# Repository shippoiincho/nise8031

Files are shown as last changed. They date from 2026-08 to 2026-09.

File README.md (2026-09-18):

# PC-8031 Emulator 偽8031

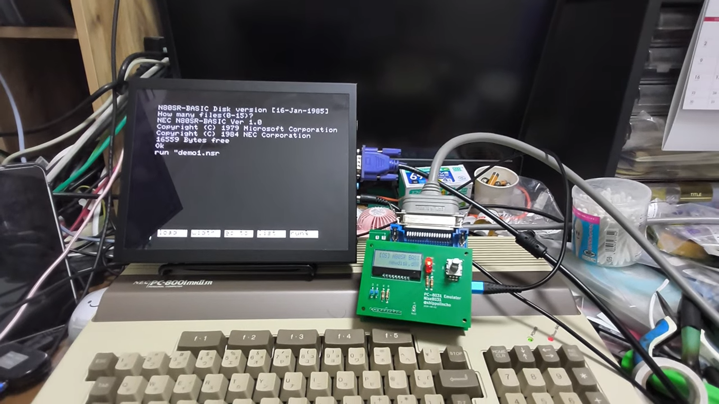
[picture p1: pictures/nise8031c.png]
board


---
# これはなに

PC-8001/8801 シリーズ用の 5インチフロッピードライブ、PC-8031 シリーズのエミュレータです。
2D ドライブのエミュレーションを行います。(PC-80S31 など相当)

PC-8001mk2SR と PC-6001mk2SR で動作確認しています。
PC-8801 でも動くと思いますが未確認です。

---
# 配線

今回はかなり複雑なので配線などは回路図を参照ください。

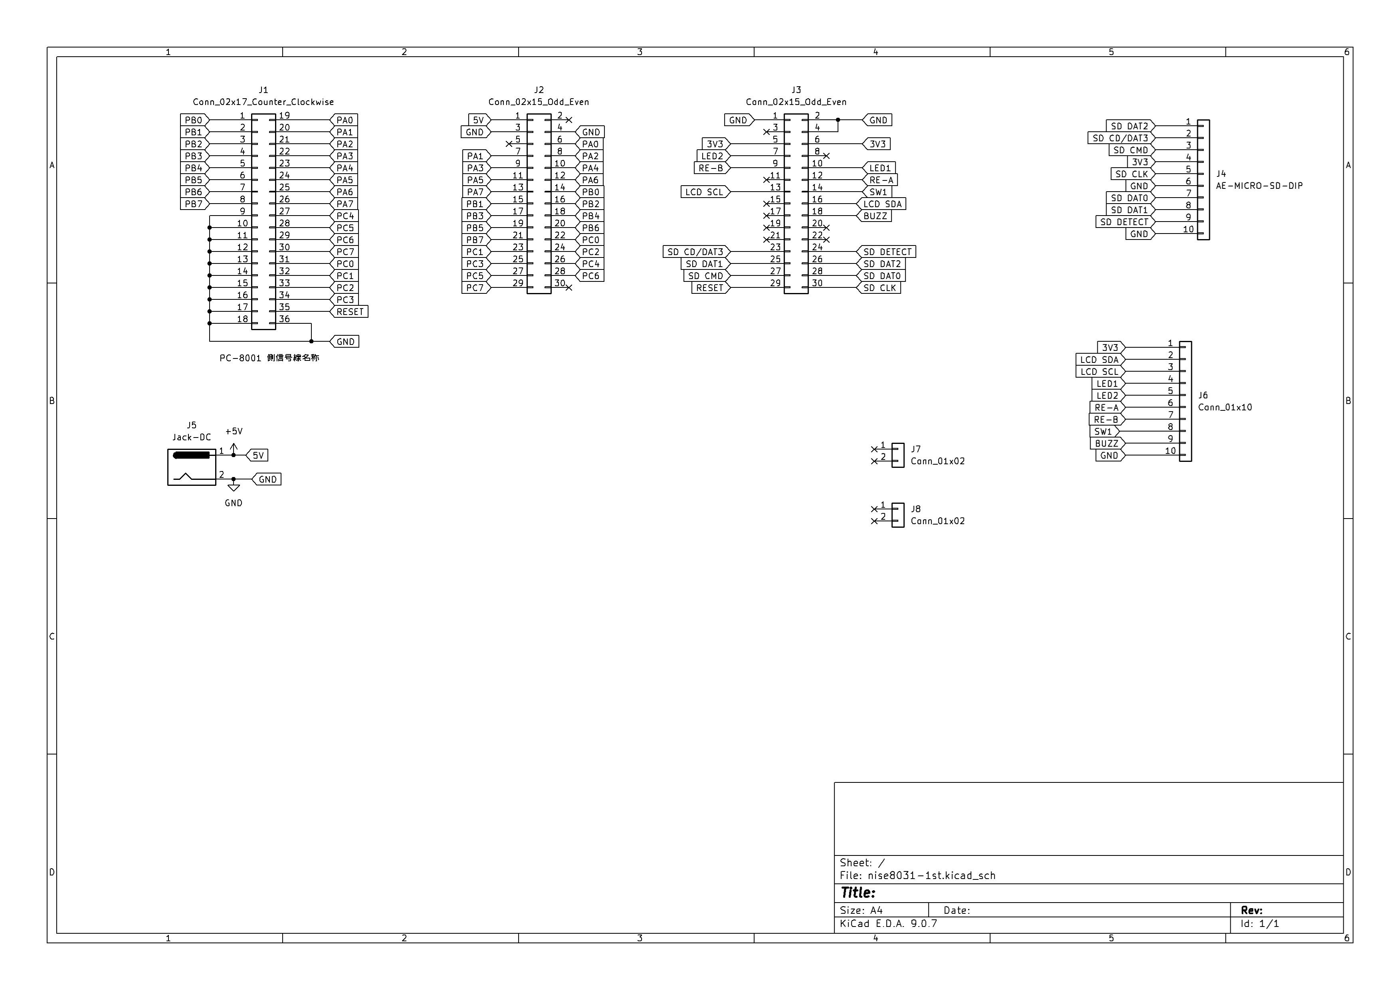
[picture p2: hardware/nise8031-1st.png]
schematics 1st

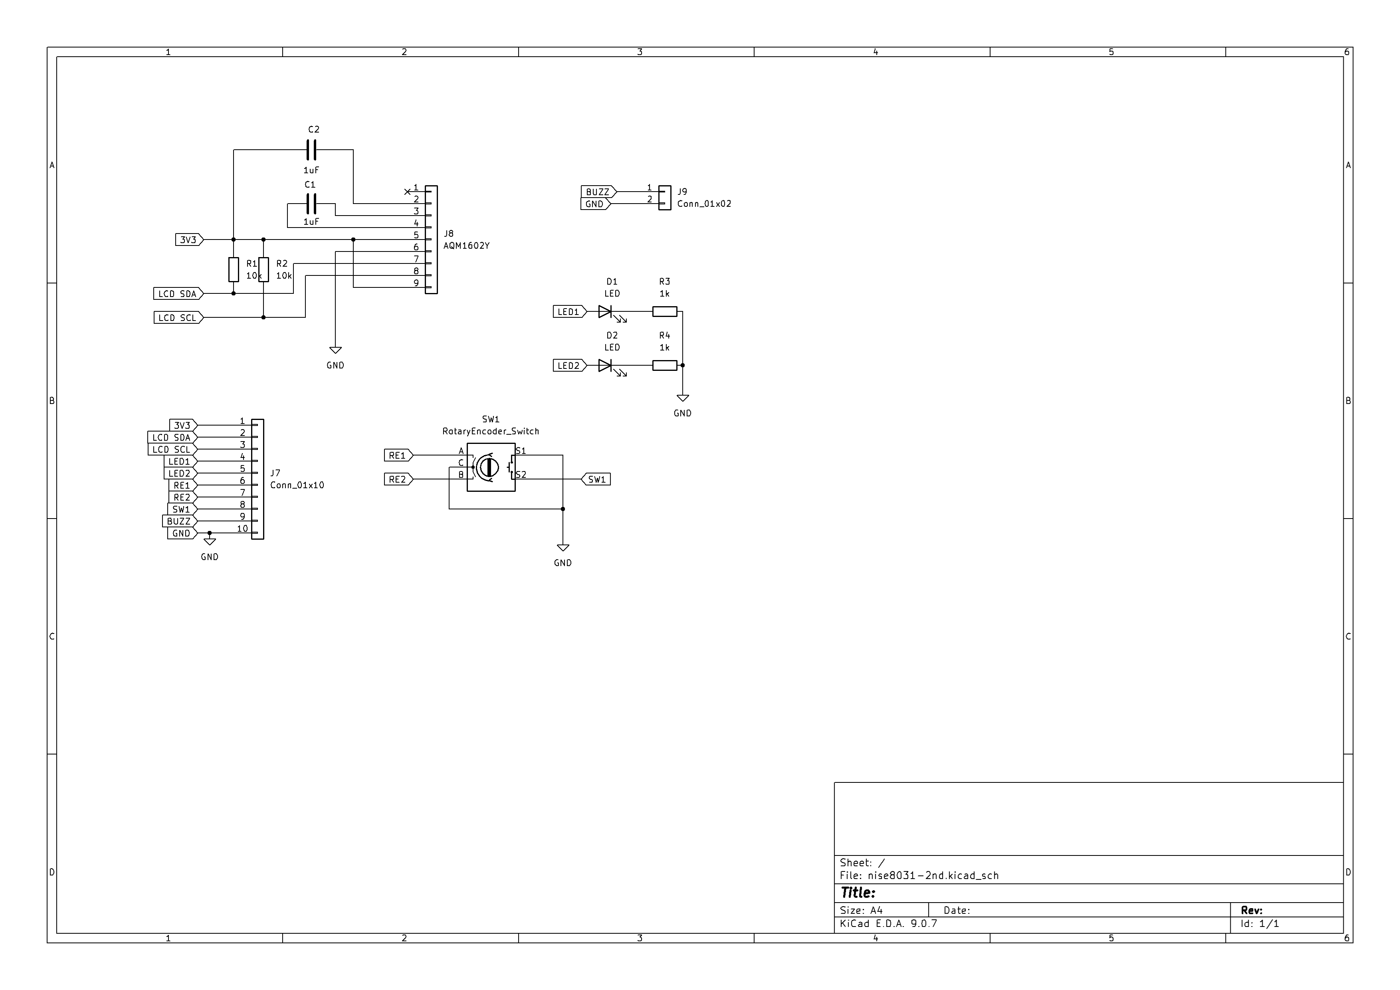
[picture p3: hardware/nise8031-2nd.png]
schematics 2nd


発注に必要な基板データは `hardware` の下にあります。

必要なパーツは以下の通りです。

- WeAct RP2350B Core Board
- [microSD DIP 化基板](https://akizukidenshi.com/catalog/g/g105488/)
- [AQM1602Y-RN-GBW](https://akizukidenshi.com/catalog/g/g111916/)
- アクセスランプ用 LED (3mm でも 5mm でもOK)
- ロータリーエンコーダ (SW 付き)
- 抵抗 1K/10K
- アンフェノールコネクタ 34Pin
- ピンヘッダ＆ソケット(基板間接続用)

基板データ上は AC アダプタの端子がありますが、
電源供給は、Pico の USB 端子を想定しています。

完成すると以下のようになるかと思います。

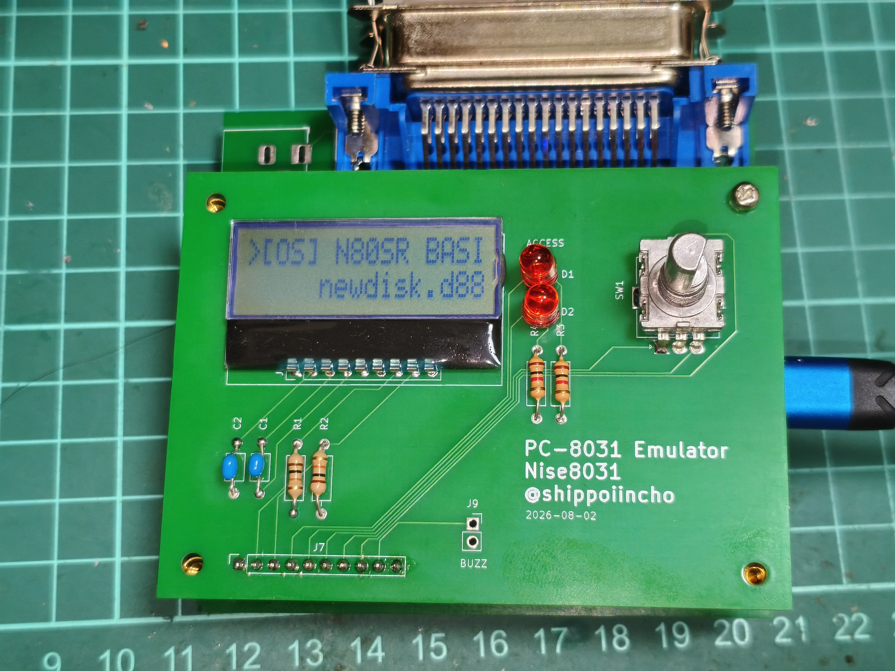
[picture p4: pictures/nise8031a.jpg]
board 2nd

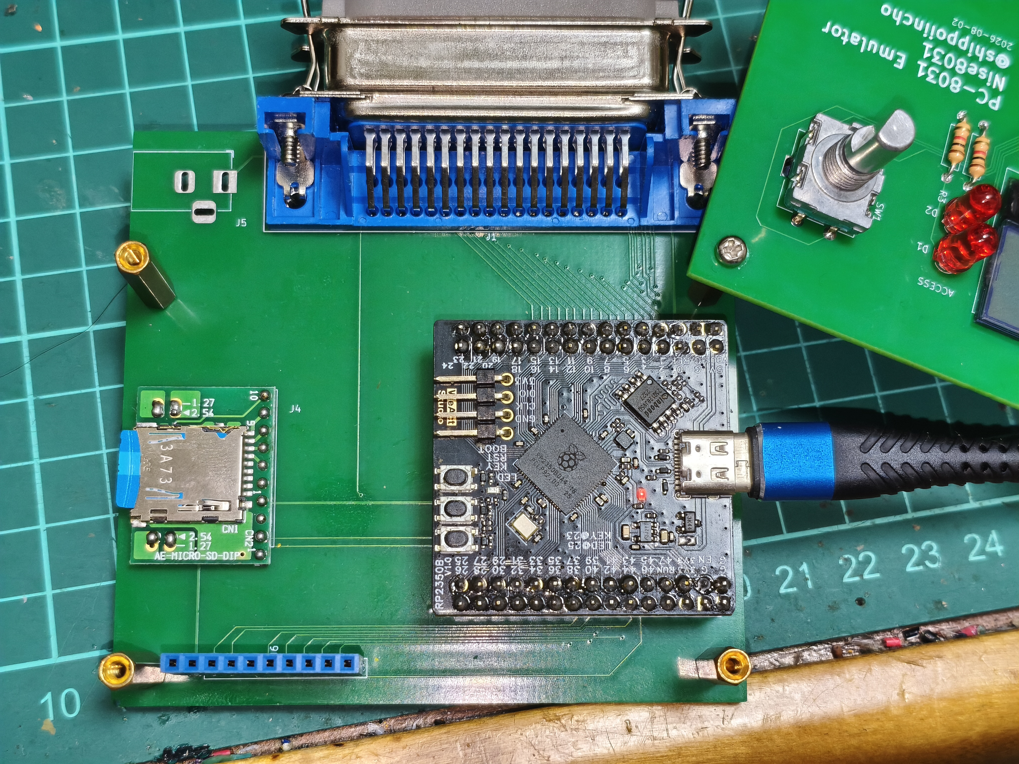
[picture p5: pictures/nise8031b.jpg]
board 1st


同じく hardware フォルダの中に、ケース用の 3Dプリンタ用データがありますので、必要であればご使用ください。
このデータは基板間を 20mm のスペーサで保持するように設計されています。
この場合基板間接続には足の長いソケットを使うとよいと思います。
(例:https://akizukidenshi.com/catalog/g/g107914/)

---
# FIRMWARE

`nise8031.uf2` を Pico のフラッシュに書き込んでください。

---
# ROM など

著作権の関係で ROM は含まれていません。

PC-80S31 (2KiB) および、PC-8801MA (8KiB) の disk.rom での動作を確認しています。
ROM ファイルを `disk.rom` というファイル名で、SD カードのルートディレクトリに置いてください。

[PC-8801 エミュレータ M88 用の pseudo bios ](http://retropc.net/cisc/m88/download.html)にも対応しました。
2D メディア専用ですが、PC-8031 シリーズ実機の ROM がなくても動作します。

---
# ディスクイメージ

エミュレータでよく使用される D88 フォーマットファイルを使用します。
microSD カード上に D88 ファイルを置いておきます。

PC-6001mk2SR 用の 1DD イメージは、内部で 2D イメージとして操作しますので、そのまま使用できると思います。

---
# 操作方法

ロータリーエンコーダを使って操作します。
基本的に回転でファイルやディレクトリを選択して、スイッチで選んだファイルやディレクトリをマウントします。
ディレクトリは `[DIR]` のように表示されます。

内部的にファイル名は 254 文字まで対応していますが、画面上では 15 文字までしか表示されません。
また`[UNMOUNT]`を選択すると、そのドライブからイメージファイルをアンマウントします。

---
# 制限事項

- フロッピーのフォーマット(しれっと無視します)は未実装です。ブランクのディスクイメージはあらかじめパソコン上のエミュレータでフォーマットしておく必要があります。
- FDC の一部のコマンドしか実装していないので、FDC を直接操作するソフトは動かない可能性があります。
- FD の動作は一瞬で完了する実装になっています。タイミングが必要なソフトで不具合が出る可能性があります。
- まれに本体起動時のハンドシェイクに失敗します。本体をリセットしなおすと起動すると思います。

---
# ライセンスなど

このエミュレータは以下のライブラリを使用しています。

- [Z80](https://github.com/redcode/Z80/tree/master)
- [Zeta](https://github.com/redcode/Zeta)
- [no-OS-FatFS-SD-SDIO-SPI-RPi-Pico](https://github.com/carlk3/no-OS-FatFS-SD-SDIO-SPI-RPi-Pico)

---

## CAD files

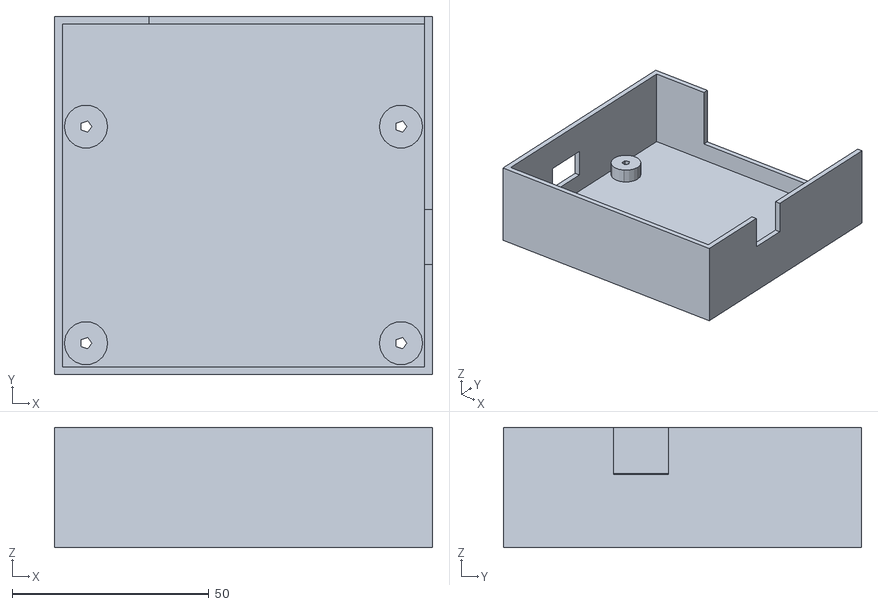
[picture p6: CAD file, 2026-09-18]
hardware/nise8031case_bottom.stl
96.0 x 91.0 x 30.6

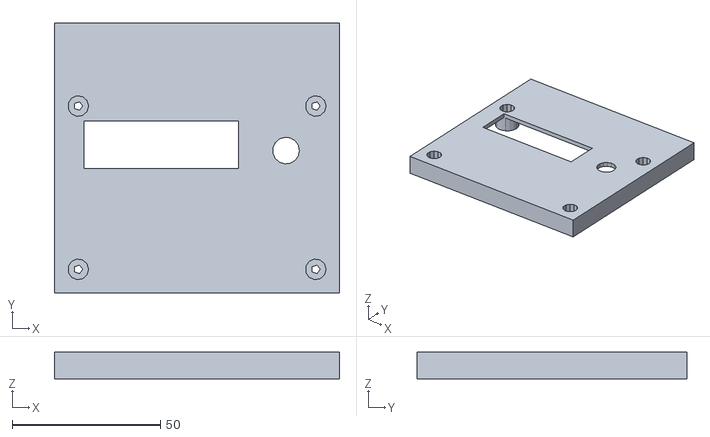
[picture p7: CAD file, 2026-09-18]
hardware/nise8031case_upper.stl
96.0 x 91.0 x 9.00

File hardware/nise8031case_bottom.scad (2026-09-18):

// nise8031 case bottom
// Base = top of 2nd floor
// Spacing of PCB = 20mm
// Shell wide = 2mm
// Bottom space = 5mm

// Bottom Outer

PCBW=1.8;
PCBS=20;
SPACE=5;
SHELLW=2.0;

difference() {



translate([-46-SHELLW,-43.5-SHELLW,-(PCBW*2+PCBS+SPACE+SHELLW)]) {    
cube([92+SHELLW*2,87+SHELLW*2,(PCBW*2+PCBS+SPACE+SHELLW)]);
};

{
translate([-46,-43.5,-(PCBW*2+PCBS+SPACE)]) {  
cube([92,87,(PCBW*2+PCBS+SPACE)]);
}

// FD connector
translate([-24,43.5,-(PCBW+PCBS)]) {       
cube([70,2,(PCBW+PCBS)]);    
}

// USB port

translate([46,-43.5+26,-12]) {
cube([2,14,12]);
}

translate([-46-SHELLW,-43.5+25,-(PCBW*2+PCBS+SPACE)+SPACE+PCBW]) {
cube([2,16,10]);
}

// SD card

// LINE OUT

//translate([-1,25,-2]) {
//
//cube([10,6,2]);
//
//}

// Bottom Holes

translate([-40,-37.5,-(PCBW*2+PCBS+SPACE+SHELLW)]) {
    
cylinder(5-SHELLW,3.5,3.5);    
       
}

translate([+40,-37.5,-(PCBW*2+PCBS+SPACE+SHELLW)]) {
    
cylinder(5-SHELLW,3.5,3.5);    
       
}

translate([-40,-37.5+55,-(PCBW*2+PCBS+SPACE+SHELLW)]) {
    
cylinder(5-SHELLW,3.5,3.5);    
       
}

translate([+40,-37.5+55,-(PCBW*2+PCBS+SPACE+SHELLW)]) {
    
cylinder(5-SHELLW,3.5,3.5);    
       
}

}
}

translate([-40,-37.5,-(PCBW*2+PCBS+SPACE)]) {

difference() {
    
cylinder(5,5.5,5.5);   
   {
    cylinder(5,1.5,1.5); 
    cylinder(5-SHELLW,3.5,3.5);     
   }
       
}
    
};

translate([+40,-37.5,-(PCBW*2+PCBS+SPACE)]) {

difference() {
    
cylinder(5,5.5,5.5);   
   {
    cylinder(5,1.5,1.5); 
    cylinder(5-SHELLW,3.5,3.5);     
   }
       
}
    
};

translate([-40,-37.5+55,-(PCBW*2+PCBS+SPACE)]) {

difference() {
    
cylinder(5,5.5,5.5);   
   {
    cylinder(5,1.5,1.5); 
    cylinder(5-SHELLW,3.5,3.5);     
   }
       
}
    
};

translate([+40,-37.5+55,-(PCBW*2+PCBS+SPACE)]) {

difference() {
    
cylinder(5,5.5,5.5);   
   {
    cylinder(5,1.5,1.5); 
    cylinder(5-SHELLW,3.5,3.5);     
   }
       
}
    
};

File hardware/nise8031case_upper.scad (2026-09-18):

// nise8031 case upper

// Bottom Outer

PCBW=1.8;
PCBS=20;
SPACE=7.0;
SHELLW=2.0;


difference() {

translate([-46-SHELLW,-43.5-SHELLW,0]) {    
cube([92+SHELLW*2,87+SHELLW*2,(SPACE+SHELLW)]);
};


translate([-46,-43.5,0]) {  
cube([92,87,SPACE]);
};

// LCD Window

translate([-46+8,-43.5+40,SPACE]) {
    
    cube([52,16,SHELLW]);    
       
}

// RE Hole

translate([-46+76,-43.5+46,SPACE]) {
    
    cylinder(SHELLW,4.5,4.5);  
       
}

// Upper Holes

translate([-40,-37.5,SPACE]) {
    
cylinder(SHELLW,3.5,3.5);    
       
}

translate([+40,-37.5,SPACE]) {
    
cylinder(SHELLW,3.5,3.5);    
       
}

translate([-40,-37.5+55,SPACE]) {
    
cylinder(SHELLW,3.5,3.5);    
       
}

translate([+40,-37.5+55,SPACE]) {
    
cylinder(SHELLW,3.5,3.5);    
       
}

}

translate([-40,-37.5,0]) {

difference() {
    
cylinder(SPACE,5.5,5.5);   
   {
    cylinder(SHELLW,1.5,1.5);
        translate([0,0,SHELLW]) {  
            cylinder(SPACE-SHELLW,3.5,3.5);     
        }
    }       
}
    
};

translate([+40,-37.5,0]) {

difference() {
    
cylinder(SPACE,5.5,5.5);   
   {
    cylinder(SHELLW,1.5,1.5);
        translate([0,0,SHELLW]) {  
            cylinder(SPACE-SHELLW,3.5,3.5);     
        }
    }       
}
    
};

translate([-40,-37.5+55,0]) {

difference() {
 
cylinder(SPACE,5.5,5.5);   
   {
    cylinder(SHELLW,1.5,1.5);
        translate([0,0,SHELLW]) {  
            cylinder(SPACE-SHELLW,3.5,3.5);     
        }
    }       
} 
 
    
};

translate([+40,-37.5+55,0]) {

difference() {

cylinder(SPACE,5.5,5.5);   
   {
    cylinder(SHELLW,1.5,1.5);
        translate([0,0,SHELLW]) {  
            cylinder(SPACE-SHELLW,3.5,3.5);     
        }
    }       
}
    
};

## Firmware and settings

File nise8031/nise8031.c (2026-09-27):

//  NEC PC-8031 floppy drive emulator
// GP0-GP7:  PPI B (Input)
// GP8-GP15: PPI A (Output)
// GP9-GP23: PPI C
// GP25: RESET
// GP26: SD CLK
// GP27: SD CMD
// GP28: SD DAT0
// GP29: SD DAT1
// GP30: SD DAT2
// GP31: SD DAT3
// GP32: SD Detect
// GP40: LCD SDA
// GP41: LCD SCL
// GP42: Rotary encoder SW
// GP44: Rotary encoder 
// GP45: Rotary encoder
// GP46: Access LED1 
// GP47: Access LED2

// DEBUG control
//#define USE_DEBUG

#include <stdio.h>
#include <stdlib.h>
#include <string.h>

#include "pico/stdlib.h"
#include "pico/multicore.h"
//#include "pico/sync.h"
#include "hardware/clocks.h"
#include "hardware/timer.h"
//#include "hardware/dma.h"
#include "hardware/uart.h"
//#include "hardware/flash.h"
//#include "hardware/sync.h"
#include "hardware/pwm.h"
#include "hardware/i2c.h"

#include "fdc.h"
#include "hw_config.h"

#include "Z80.h"

#include "lcd.h"

#define RESET_PIN 25
#define RE_SW   42
#define RE_A    44
#define RE_B    45
#define LCD_SDA 40
#define LCD_SCL 41

struct repeating_timer timer,timer2;

// WAIT cycles to interrupt
#define FDC_INTERRUPT_INTERVAL 100

// PC configuration

static Z80 cpu;
uint32_t cpu_clocks=0;
uint32_t cpu_ei=0;
uint32_t cpu_cycles=0;
uint32_t cpu_hsync=0;
uint32_t interrupt_cycles;

uint8_t mainram[0x10000];
uint8_t ioport[0x100];

volatile uint32_t timer_count;
struct repeating_timer timer;

volatile uint8_t fdu_init=0;

// UI

#define RE_DELAY 2
#define MENU_TIMEOUT 5000
uint32_t re_a_count;
uint32_t re_b_count;
uint32_t re_sw_count;
bool re_a_state=true;
bool re_b_state=true;
bool re_sw_state=true;

volatile uint32_t menumode=0;   // 0:normal 1:select drive 2:select file
volatile uint32_t menucount=0;

uint32_t menuitem=0;
uint32_t numitems=0;
uint32_t menuselected=0;
uint32_t menudrive=1;

unsigned char lcd_line1[256];
unsigned char lcd_line2[256];
unsigned char lcd_prompt1=0x20;
unsigned char lcd_prompt2=0x20;

volatile uint8_t disk_change=0;

// PC-8031 ROM filename
const uint8_t romfilename[]="disk.rom";

// config file to mount
// directory1
// filename2
// directory2
// filename2
const uint8_t configfile[]="config.txt";

uint8_t fd_directory1[256];
uint8_t fd_directory2[256];
uint8_t fd_filename1[256];
uint8_t fd_filename2[256];
uint8_t fd_filename[256];
uint8_t fd_menu_drive=0;

#define PPI_DELAY 50

// FatFS configuration

    FATFS fs;
    FIL fdtmp;

/* SDIO Interface */
static sd_sdio_if_t sdio_if = {
    /*
    Pins CLK_gpio, D1_gpio, D2_gpio, and D3_gpio are at offsets from pin D0_gpio.
    The offsets are determined by sd_driver\SDIO\rp2040_sdio.pio.
        CLK_gpio = (D0_gpio + SDIO_CLK_PIN_D0_OFFSET) % 32;
        As of this writing, SDIO_CLK_PIN_D0_OFFSET is 30,
            which is -2 in mod32 arithmetic, so:
        CLK_gpio = D0_gpio -2.
        D1_gpio = D0_gpio + 1;
        D2_gpio = D0_gpio + 2;
        D3_gpio = D0_gpio + 3;
    */
    .CMD_gpio = 27,
    .D0_gpio = 28,
    .baud_rate = 125 * 1000 * 1000 / 6  // 20833333 Hz
};

/* Hardware Configuration of the SD Card socket "object" */
static sd_card_t sd_card = {.type = SD_IF_SDIO, .sdio_if_p = &sdio_if};

size_t sd_get_num() { return 1; }

sd_card_t* sd_get_by_num(size_t num) {
    if (0 == num) {
        // The number 0 is a valid SD card number.
        // Return a pointer to the sd_card object.
        return &sd_card;
    } else {
        // The number is invalid. Return @c NULL.
        return NULL;
    }
}

//
//  Timer

bool __not_in_flash_func(timer_handler)(struct repeating_timer *t) {

    timer_count++;

    return true;
}

#if 0
// Rotary Encoder interrupts
// GPIO IRQ

void __not_in_flash_func(irq_callback)(uint gpio,uint32_t event) {

    bool resw,rea,reb;

    switch(gpio) {

        case RE_A:

//            gpio_acknowledge_irq(RE_A,event);
//            gpio_acknowledge_irq(RE_A,GPIO_IRQ_EDGE_FALL);
            
            rea=gpio_get(RE_A);
            reb=gpio_get(RE_B);

            sleep_us(10);

            if((rea!=gpio_get(RE_A))||(reb!=gpio_get(RE_B))) {
                return;
            }

            if(gpio_get(RE_A) ^ gpio_get(RE_B)) {
                printf("[RE+]");
            } else {
            printf("[RE-]");
            }

            return;

        case RE_SW:

//            gpio_acknowledge_irq(RE_SW,GPIO_IRQ_EDGE_FALL);

            resw=gpio_get(RE_SW);
            sleep_us(100);
            if(resw!=gpio_get(RE_SW)) {
                return;
            }

            printf("[SW:on]");

            return;


        default:
            return;

    }

}
#endif

uint8_t encoder_check() {

    uint8_t val;

    val=0;

    // check SW

    if(re_sw_state!=gpio_get(RE_SW)) {
        if((timer_count-re_sw_count)>RE_DELAY) {
            if(re_sw_state==true) { // Falling
#ifdef DEBUG
                printf("[SW:on]");
#endif
                val=1;
            }
            re_sw_state=!re_sw_state;
        }
    } else {
        re_sw_count=timer_count;
    }

    // check RE

    if(re_a_state!=gpio_get(RE_A)) {
        if((timer_count-re_a_count)>RE_DELAY) {
            if(re_a_state==false) {
                if(re_b_state==true) {
#ifdef DEBUG
                    printf("[RE:+]");
#endif
                    val|=4;
                } else {
#ifdef DEBUG
                    printf("[RE:-]");
#endif
                    val|=2;
                }
            }   // EC11 encoder make 1 pluse for 1 click
            // else {
            //     if(re_b_state==false) {
            //         printf("[RE:+]");
            //     } else {
            //         printf("[RE:-]");
            //     }                
            // }

            re_a_state=!re_a_state;
        }
    } else {
        re_a_count=timer_count;
    }

    if(re_b_state!=gpio_get(RE_B)) {
        if((timer_count-re_b_count)>RE_DELAY) {
            re_b_state=!re_b_state;
        }
    } else {
        re_b_count=timer_count;
    }

    return val;

}



//
//  reset

void __not_in_flash_func(z80reset)(uint gpio,uint32_t event) {

//    gpio_acknowledge_irq(RESET_PIN,GPIO_IRQ_EDGE_FALL);
    gpio_acknowledge_irq(RESET_PIN,GPIO_IRQ_EDGE_RISE);

    fdc_init();
    z80_power(&cpu,TRUE);
    memset(ioport,0,256);
//    memset(mainram,0,0x10000);
//    memcpy(mainram,mainrom,0x2000);

//    gpio_put_masked(0xff,0);
//    gpio_put_masked(0xf0000,0);

    fdu_init=1;

    return;

}

//

void display_init(void) {

    i2c_init(i2c_default, 100 * 1000);
    gpio_set_function(LCD_SDA, GPIO_FUNC_I2C);
    gpio_set_function(LCD_SCL, GPIO_FUNC_I2C);
    gpio_pull_up(LCD_SDA);
    gpio_pull_up(LCD_SCL);

    lcd_init();

    return;

}

void display_file(void) {

    unsigned char string[32];
    
    lcd_clear();

    if((menumode!=0)&&(menudrive==1)) {
        snprintf(string,17,"%c%-15s",'>',lcd_line1);            
    } else {
        snprintf(string,17,"%c%-15s",' ',lcd_line1);             
    }
    lcd_set_cursor(0,0);
    lcd_string(string);

    if((menumode!=0)&&(menudrive==2)) {
        snprintf(string,17,"%c%-15s",'>',lcd_line2);            
    } else {
        snprintf(string,17,"%c%-15s",' ',lcd_line2);             
    }

    lcd_set_cursor(1,0);
    lcd_string(string);

    return;

}

// get number of entries

int32_t get_directory(uint8_t *directory,uint8_t *filename) {

    DIR dir;
    FILINFO finfo;
    int32_t numfiles;
    FRESULT fr;

    numfiles=0;

    fr=f_opendir(&dir,directory);

    if(fr!=FR_OK) {
        return -1;
    }    

    while(1) {

        fr=f_readdir(&dir,&finfo);
#ifdef DEBUG
        printf("%d %s\n\r",finfo.fattrib,finfo.fname); 
#endif
        if(strcmp(finfo.fname,"")!=0) {

            // ignore system file (eg. "System Volume Information")

            if(finfo.fattrib&AM_SYS) {
                continue;
            }

            // ignore ROM and config file

            if(strcmp(finfo.fname,romfilename)==0) {
                continue;
            }
            if(strcmp(finfo.fname,configfile)==0) {
                continue;
            }

            numfiles++;

            if(strcmp(finfo.fname,filename)==0) {
                menuselected=numfiles;
            }

        } else {
            break;
        }


   }

   f_closedir(&dir);

   return numfiles;

}

//

int32_t get_filename(uint8_t *directory,uint32_t number) {

    DIR dir;
    FILINFO finfo;
    FRESULT fr;
    int32_t numfiles;

    numfiles=0;

    if(number==0) {
        strcpy(fd_filename,"..");
        return AM_DIR;
    }

    if(number==numitems+1) {
        strcpy(fd_filename,"UNMOUNT");
        return 255;
    }

    fr=f_opendir(&dir,directory);

    if(fr!=FR_OK) {
        return -1;
    }    

    while(1) {

        fr=f_readdir(&dir,&finfo);
#ifdef DEBUG        
        printf("%d %s\n\r",finfo.fattrib,finfo.fname);
#endif
        if(strcmp(finfo.fname,"")!=0) {

            // ignore system file (eg. "System Volume Information")

            if(finfo.fattrib&AM_SYS) {
                continue;
            }

            // ignore ROM and config file

            if(strcmp(finfo.fname,romfilename)==0) {
                continue;
            }
            if(strcmp(finfo.fname,configfile)==0) {
                continue;
            }

            numfiles++;
            if(numfiles==number) {
                sprintf(fd_filename,"%s",finfo.fname);
                if(finfo.fattrib&AM_DIR) {
                    return AM_DIR;
                } else {
                    return 0;
                }
            }

        } else {
            break;
        }

   }

   f_closedir(&dir);

   return 0;
  
    // return
    // 0:file
    // 0x10:directory

}

void updir(unsigned char *str) {

    int32_t ptr;

    ptr=strlen(str);
#ifdef DEBUG
    printf("[%s]->",str);
#endif
    if(ptr<1) return;

    while(ptr>0){
        if(str[ptr]=='/') {
            str[ptr]=0;
#ifdef DEBUG
            printf("[%s]\n\r",str);
#endif
            return;
            
        }
        ptr--;
    }

    strcpy(str,"/");

    return;
}

int32_t saveconfig(void) {

    FRESULT fr;

    fr=f_open(&fdtmp,configfile,FA_READ|FA_WRITE|FA_CREATE_ALWAYS);

    if (FR_OK == fr) {
        f_printf(&fdtmp,"%s\n",fd_directory1);
        f_printf(&fdtmp,"%s\n",fd_filename1);
        f_printf(&fdtmp,"%s\n",fd_directory2);
        f_printf(&fdtmp,"%s\n",fd_filename2);
        f_close(&fdtmp);

        return 0;
    }

    return -1;


}



static inline uint8_t mem_read(void *context,uint16_t address)
{

    if(address<0x8000) {
        return mainram[address];
    }

    return 0xff;

}

static inline void mem_write(void *context,uint16_t address, uint8_t data)
{

    if((address>=0x4000)&&(address<0x8000)) {
        mainram[address]=data;
    }

    return;

}

static inline uint8_t io_read(void *context, uint16_t address)
{
    uint8_t data = ioport[address&0xff];
    uint8_t b;
    uint32_t gpio_data;


    if((address&0xff)!=0xfe) {
//        printf("[IOR %02x:%04x]",address&0xff,Z80_PC(cpu));
    }
        // if((address&0xf0)==0xe0) {
        // printf("[IOR:%04x:%02x]",Z80_PC(cpu),address&0xff);
        // }

    switch(address&0xff) {

        case 0xf8:  // TC
#ifdef USE_DEBUG
        printf("[TC]");
#endif
        fdc_tc();

            return 0xff;

        case 0xfa:  // FDC status
        
            return fdc_status();

        case 0xfb:  // FDC Data

            return fdc_command_read();

        case 0xfc:  // PPI A

            gpio_data=gpio_get_all();

            gpio_data&=0xff00;
            gpio_data>>=8;

#ifdef USE_DEBUG
//            if(gpio_data!=0) {
            if(gpio_data==0) {
                printf("[PR:%02x]",gpio_data);
            }
#endif
            return gpio_data;

        case 0xfd:  // PPI B

            return ioport[0xfd];

        case 0xfe:  // PPI C

            gpio_data=gpio_get_all()&0xf00000;

//        printf("[%x]",gpio_data);
            
            gpio_data>>=20;

            ioport[0xfe]&=0xf0;
            ioport[0xfe]|=gpio_data;

            sleep_us(PPI_DELAY);

            // if(ppidebug != ioport[0xfe]) {
            //     printf("[SR:%02x:%04x]",ioport[0xfe],Z80_PC(cpu));
            // ppidebug=ioport[0xfe];
            // }


#if DEBUG            

if((ioport[0xfe]&0xf)!=0) {
        printf("[SR:%02x]",ioport[0xfe]);
}
#endif

            return ioport[0xfe];

        case 0xff:  // PPI Control
            return ioport[address&0xff];

        default:
            return 0xff;

    }

//   return 0xff;
}

static inline void io_write(void *context, uint16_t address, uint8_t data)
{

    uint8_t b;

#ifdef USE_DEBUG
    if((address&0xff)!=0xff) {
    printf("[IOW %02x:%02x]",address&0xff,data);
    }
#endif

    // if((address&0xf0)==0xf0) {
    // printf("[IOW:%04x:%02x:%02x->%02x]",Z80_PC(cpu),address&0xff,ioport[address&0xff],data);
    // }

    switch(address&0xff) {

        case 0xf8:  // Motor
            ioport[0xf8]=data;
            return;

        case 0xfa:  // FDC data

            return;


        case 0xfb:  // FDC command
            fdc_command_write(data);
            return;

        case 0xfd:  // PPI B

            gpio_put_masked(0xff,data);
#ifdef USE_DEBUG
            printf("{%02x}",data);
#endif
            ioport[0xfd]=data;
            return;

        case 0xfe:  // PPI C

            gpio_put_masked(0xf0000,(data&0xf0)<<12);
            ioport[0xfe]&=0xf;
            ioport[0xfe]|=data&0xf0;

            return;

        case 0xff:

            if((data&0x80)==0) { // Bit operation

                b=(data&0x0e)>>1;

                if(data&1) {
                    ioport[0xfe]|= 1<<b;
                } else {
                    ioport[0xfe]&= ~(1<<b);
                }

                gpio_put_masked(0xf0000,(((uint32_t)(ioport[0xfe])&0xf0)<<12));
#ifdef DEBUG
        printf("[SW:%02x]",ioport[0xfe]);
//                printf("[%x]",gpio_get_all());
#endif            
            }

            return;

        default:
            ioport[address&0xff]=data;
            return;

    }


}

static uint8_t ird_read(void *context,uint16_t address) {

    // PC-8031 use Mode 0 and return NOP(00)

    z80_int(context,FALSE);

    return 0;

}

#if 0
static void reti_callback(void *context) {

}
#endif

void init_emulator(void) {
    //  setup emulator 
    // COPY DISK ROM to RAM
    // Maximum 8Kib
    //    memcpy(mainram,mainrom,0x2000);
}

void main_core1(void) {

    uint32_t    gpio_data;

//    multicore_lockout_victim_init();

//    gpio_set_irq_enabled(RESET_PIN,GPIO_IRQ_EDGE_RISE, true);
    gpio_set_irq_enabled_with_callback(RESET_PIN,GPIO_IRQ_EDGE_RISE,true,z80reset);

    // RUN Z80 EMULATION on Core1

    init_emulator();

    fdu_init=1;

    cpu.read = mem_read;
    cpu.write = mem_write;
    cpu.in = io_read;
    cpu.out = io_write;
	cpu.fetch = mem_read;
    cpu.fetch_opcode = mem_read;
//    cpu.reti = reti_callback;
    cpu.inta = ird_read;

    z80_power(&cpu,true);
    z80_instant_reset(&cpu);

    cpu_hsync=0;
    cpu_cycles=0;

    while(1) {

        if(fdu_init) {

            // Wait PC is ready

            while(1) {
                gpio_put_masked(0xf00ff,0);
                sleep_ms(10);
        
                gpio_data=gpio_get_all()&0xf00000;
                if(gpio_data!=0xf00000) {
                    fdu_init=0;    
                    break;
                }
            }
        }

        cpu_cycles += z80_run(&cpu,1);
        cpu_clocks++;

        if(fdc_interrupt_flag==1) {
            fdc_interrupt_flag=2;
            interrupt_cycles = cpu_clocks + FDC_INTERRUPT_INTERVAL;
        } 
        if((fdc_interrupt_flag==2)&&(cpu_clocks>interrupt_cycles)) {
            fdc_interrupt_flag=0;
            z80_int(&cpu,TRUE);
        }

    }
}

int main() {

    uint32_t menuprint=0;
//    uint32_t filelist=0;
    UINT bytes_read;
    uint8_t encoder;
    unsigned char filename[256];
    unsigned char dirname[256];
    int32_t ftype;

//    set_sys_clock_khz(300000 ,true);

    stdio_init_all();

    gpio_init_mask(0xffffffff);
    gpio_set_dir_all_bits(0x0f00ff);

    display_init();

    gpio_init(46);
    gpio_init(47);
    gpio_set_dir(46,true);
    gpio_set_dir(47,true);
    gpio_put(46,false);
    gpio_put(47,false);

    fdc_init();

//  Initialize FatFs

    // See FatFs - Generic FAT Filesystem Module, "Application Interface",
    // http://elm-chan.org/fsw/ff/00index_e.html

    FRESULT fr = f_mount(&fs, "", 1);
    if (FR_OK != fr) {
        lcd_clear();
        lcd_set_cursor(0,0);
        lcd_string("Can not mount SD card");
        panic("f_mount error: %s (%d)\n", FRESULT_str(fr), fr);

        return -1;
    }

    // READ ROM File

    fr=f_open(&fdtmp,romfilename,FA_READ);

    if (FR_OK != fr) {
        lcd_clear();
        lcd_set_cursor(0,0);
        lcd_string("Can not read rom file");
        panic("f_open error: %s (%d)\n", FRESULT_str(fr), fr);
        return -1;
    }

    f_read(&fdtmp,mainram,8192,&bytes_read);

    f_close(&fdtmp);

    // Overwrite drive type (for pseudo bios)

    mainram[0x7ef]=0xef;

    // READ Config file

    fr=f_open(&fdtmp,configfile,FA_READ);

    if (FR_OK == fr) {

        f_gets(fd_directory1,255,&fdtmp);
        f_gets(fd_filename1,255,&fdtmp);
        f_gets(fd_directory2,255,&fdtmp);
        f_gets(fd_filename2,255,&fdtmp);        

        // remove tailing newline
        fd_directory1[strcspn(fd_directory1, "\r\n")] = 0;
        fd_filename1[strcspn(fd_filename1, "\r\n")] = 0;
        fd_directory2[strcspn(fd_directory2, "\r\n")] = 0;
        fd_filename2[strcspn(fd_filename2, "\r\n")] = 0;

        f_close(&fdtmp);

    } else {
        // Can not read config file

        strcpy(fd_directory1,"/");
        strcpy(fd_directory2,"/");

        fd_filename1[0]=0;
        fd_filename2[0]=0;

    }

    // Initialize Rotary Encoder

    gpio_init(RE_SW);
    gpio_init(RE_A);
    gpio_init(RE_B);

    gpio_set_dir(RE_SW,false);
    gpio_set_dir(RE_A,false);
    gpio_set_dir(RE_B,false);

    gpio_set_pulls(RE_SW,true,false);
    gpio_set_pulls(RE_A,true,false);
    gpio_set_pulls(RE_B,true,false); 
 
//    gpio_set_irq_callback(irq_callback);

//    gpio_set_irq_enabled(RE_A,GPIO_IRQ_EDGE_RISE|GPIO_IRQ_EDGE_FALL,true);
//    gpio_set_irq_enabled(RE_SW,GPIO_IRQ_EDGE_FALL,true);

//    irq_set_enabled(IO_IRQ_BANK0,true);

    // timer (1 msec)
    add_repeating_timer_us(1000,timer_handler,NULL  ,&timer);

    // Beep & PSG

#if 0
    gpio_set_function(6,GPIO_FUNC_PWM);
 //   gpio_set_function(11,GPIO_FUNC_PWM);
    pwm_slice_num = pwm_gpio_to_slice_num(6);

    pwm_set_wrap(pwm_slice_num, 256);
    pwm_set_chan_level(pwm_slice_num, PWM_CHAN_A, 0);
//    pwm_set_chan_level(pwm_slice_num, PWM_CHAN_B, 0);
    pwm_set_enabled(pwm_slice_num, true);
#endif

    multicore_launch_core1(main_core1);   
//    multicore_lockout_victim_init();

//  Image file mount

    strcpy(lcd_line1,"[EMPTY]");
    if(fd_filename1[0]!=0) {
        if(strcmp(fd_directory1,"/")==0) {
            snprintf(filename,255,"%s",fd_filename1);
        } else {
            snprintf(filename,255,"%s/%s",fd_directory1,fd_filename1);
        }
        fr=f_open(fd_drive[0],filename,FA_READ|FA_WRITE);

        if (FR_OK == fr) {
            fdc_check(0);
            strncpy(lcd_line1,fd_filename1,255);            
        } else {
            strcpy(fd_directory1,"/");
            fd_filename1[0]=0;
        }
    }

    strcpy(lcd_line2,"[EMPTY]");
    if(fd_filename2[0]!=0) {
        if(strcmp(fd_directory2,"/")==0) {
            snprintf(filename,255,"%s",fd_filename2);
        } else {
            snprintf(filename,255,"%s/%s",fd_directory2,fd_filename2);
        }
        fr=f_open(fd_drive[1],filename,FA_READ|FA_WRITE);

        if (FR_OK == fr) {
            fdc_check(1);
            strncpy(lcd_line2,fd_filename2,255);            
        } else {
            strcpy(fd_directory2,"/");
            fd_filename2[0]=0;            
        }
    }    

    display_file();

#ifdef DEBUG
    printf("[Drive1:%x,%x]",fd_drive_status[0],fd_media_type[0]);
    printf("[Drive2:%x,%x]",fd_drive_status[1],fd_media_type[1]);
#endif

    menumode=0;

    while(1){

        encoder=encoder_check();

        switch(menumode) {

            case 0:
                // enter menu mode
                if(encoder&1) {
                    menumode=1;
                    menucount=timer_count;
                    display_file();                    
                }

                break;

            case 1:

                if(encoder&1) {
                    menumode=2;
                    menucount=timer_count;
                    menuselected=1;
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

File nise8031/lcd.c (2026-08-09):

// i2c LCD control
// Based on pico-example//i2c/lcd_1602_i2c

#include <stdio.h>
#include <string.h>
#include "pico/stdlib.h"
#include "hardware/i2c.h"

// commands
const int LCD_CLEARDISPLAY = 0x01;
const int LCD_RETURNHOME = 0x02;
const int LCD_ENTRYMODESET = 0x04;
const int LCD_DISPLAYCONTROL = 0x08;
const int LCD_CURSORSHIFT = 0x10;
const int LCD_FUNCTIONSET = 0x20;
const int LCD_SETCGRAMADDR = 0x40;
const int LCD_SETDDRAMADDR = 0x80;

// flags for display entry mode
const int LCD_ENTRYSHIFTINCREMENT = 0x01;
const int LCD_ENTRYLEFT = 0x02;

// flags for display and cursor control
const int LCD_BLINKON = 0x01;
const int LCD_CURSORON = 0x02;
const int LCD_DISPLAYON = 0x04;

// flags for display and cursor shift
const int LCD_MOVERIGHT = 0x04;
const int LCD_DISPLAYMOVE = 0x08;

// flags for function set
const int LCD_5x10DOTS = 0x04;
const int LCD_2LINE = 0x08;
const int LCD_8BITMODE = 0x10;
const int LCD_IS = 0x01;

// flag for backlight control
const int LCD_BACKLIGHT = 0x08;

const int LCD_ENABLE_BIT = 0x04;

static int addr = 0x3e;

// Modes for lcd_send_byte
const int LCD_CHARACTER = 0x40;
const int LCD_COMMAND = 0;

#define MAX_LINES      2
#define MAX_CHARS      16

#define LCD_DELAY      30

/* Quick helper function for single byte transfers */
void i2c_write_byte(uint8_t val) {
#ifdef i2c_default
    i2c_write_blocking(i2c_default, addr, &val, 1, false);
#endif
}

void lcd_send_byte(uint8_t val, int mode) {
    uint8_t data[2];
    data[0]=mode;
    data[1]=val;
#ifdef i2c_default
    i2c_write_blocking(i2c_default, addr, data, 2, false);
#endif
    sleep_us(LCD_DELAY);
}


void lcd_clear(void) {
    lcd_send_byte(LCD_CLEARDISPLAY, LCD_COMMAND);
}

// go to location on LCD
void lcd_set_cursor(int line, int position) {
    int val = (line == 0) ? 0x80 + position : 0xC0 + position;
    lcd_send_byte(val, LCD_COMMAND);
}

static inline void lcd_char(char val) {
    lcd_send_byte(val, LCD_CHARACTER);
}

void lcd_string(const char *s) {
    while (*s) {
        lcd_char(*s++);
    }
}

void lcd_init() {
    lcd_send_byte(0x03, LCD_COMMAND);
    lcd_send_byte(0x03, LCD_COMMAND);
    lcd_send_byte(0x03, LCD_COMMAND);
    lcd_send_byte(0x02, LCD_COMMAND);

    lcd_send_byte(LCD_ENTRYMODESET | LCD_ENTRYLEFT, LCD_COMMAND);
    lcd_send_byte(LCD_FUNCTIONSET | LCD_2LINE | LCD_8BITMODE , LCD_COMMAND);
    lcd_send_byte(LCD_FUNCTIONSET | LCD_2LINE | LCD_8BITMODE | LCD_IS , LCD_COMMAND);

    lcd_send_byte( 0x14, LCD_COMMAND) ;
    lcd_send_byte( 0x70, LCD_COMMAND) ;
    lcd_send_byte( 0x56, LCD_COMMAND) ;
    lcd_send_byte( 0x6c, LCD_COMMAND) ;

    sleep_us(1000);

    lcd_send_byte(LCD_FUNCTIONSET | LCD_2LINE | LCD_8BITMODE , LCD_COMMAND);

    lcd_send_byte(LCD_DISPLAYCONTROL | LCD_DISPLAYON, LCD_COMMAND);
    lcd_clear();

}

#if 0
int main() {
#if !defined(i2c_default) || !defined(PICO_DEFAULT_I2C_SDA_PIN) || !defined(PICO_DEFAULT_I2C_SCL_PIN)
    #warning i2c/lcd_1602_i2c example requires a board with I2C pins
#else
    // This example will use I2C0 on the default SDA and SCL pins (4, 5 on a Pico)
    i2c_init(i2c_default, 100 * 1000);
    gpio_set_function(PICO_DEFAULT_I2C_SDA_PIN, GPIO_FUNC_I2C);
    gpio_set_function(PICO_DEFAULT_I2C_SCL_PIN, GPIO_FUNC_I2C);
    gpio_pull_up(PICO_DEFAULT_I2C_SDA_PIN);
    gpio_pull_up(PICO_DEFAULT_I2C_SCL_PIN);
    // Make the I2C pins available to picotool
    bi_decl(bi_2pins_with_func(PICO_DEFAULT_I2C_SDA_PIN, PICO_DEFAULT_I2C_SCL_PIN, GPIO_FUNC_I2C));

    lcd_init();

    static char *message[] =
            {
                    "RP2040 by", "Raspberry Pi",
                    "A brand new", "microcontroller",
                    "Twin core M0", "Full C SDK",
                    "More power in", "your product",
                    "More beans", "than Heinz!"
            };

    while (1) {
        for (uint m = 0; m < sizeof(message) / sizeof(message[0]); m += MAX_LINES) {
            for (int line = 0; line < MAX_LINES; line++) {
                lcd_set_cursor(line, (MAX_CHARS / 2) - strlen(message[m + line]) / 2);
                lcd_string(message[m + line]);
            }
            sleep_ms(2000);
            lcd_clear();
        }
    }
#endif
}
#endif

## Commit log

2026-08-09 Access LED
2026-08-23 Add board pictures
2026-09-12 Add wait for stability
    [nise8031case_bottom.scad, nise8031case_upper.scad]
2026-09-18 Add shell STL files
    [nise8031case_bottom.scad, nise8031case_bottom.stl, nise8031case_upper.scad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]
2026-09-27 fix image is read only for power-on mount
    [nise8031.c]
